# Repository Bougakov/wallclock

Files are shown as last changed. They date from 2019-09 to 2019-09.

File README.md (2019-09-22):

# Firmware for the clock in the hallway of http://sch57.ru

This is a firmware for a giant clock made of multiple layers of plywood and acrylic and five meters of "WS2812b" ("Neopixel") LED strip. It uses GPS module to set the correct time from satellites on the startup. RTC module ("DS1307") is used for timekeeping. 

During the lessons and in after-school hours it displays current time; during the breaks it acts as a count-down timer.

This clock is a part of a large-scale redesign of School 57 by a Russian architect and designer, Mia Karlova, which won the "Best public space" award by AD Magazine in https://www.admagazine.ru/ad-design-award/novyj-oblik-moskovskoj-shkoly-57 and was featured in FRAME magazine: https://www.frameweb.com/news/moscow-school-57-mia-karlova

Assembled clock on the wall

[Click to view video on Instagram: Preview - Instagram](https://www.instagram.com/p/BxpXTDVDegR/)

Initally, a large TV screen was used instead of this clock:

Old TV was replaced with this clock

The clock can be assembled from laser-cut sheets of 3-4mm plywood. The [layouts (in AutoCAD format)](https://github.com/Bougakov/wallclock/tree/master/CAD%20files%20%28plywood%20lasercut%29) are designed in such a way that any laser cutter with working area of as low as 300x600mm could be used. Few dozen of 40mm M3 screws are needed for assembly. Diffusors are made of 2mm matte acrylic.

[Click to view video on Instagram: Countdown - Instagram](https://www.instagram.com/p/B2cq6O_Ikv1/)

Click the preview of the AutoCAD drawing to read more on the assembly:

AutoCAD drawing in full glory

## Wiring

* GPS is connected (via "MAX232" RS232 to TTL converter) to `D3` pin of Arduino. Don't forget to double-check the baud rate of your GPS.
* LED strip (288 "WS2812" LEDs) – to pin `D2`.
  * Each "digit" is made of 7 segments, 10 LEDs each. 
  * "Colon" in the middle is made of 2 segments, 4 LEDs each.
* Controller – an Arduino Nano (Atmega 328P, "old bootloader")

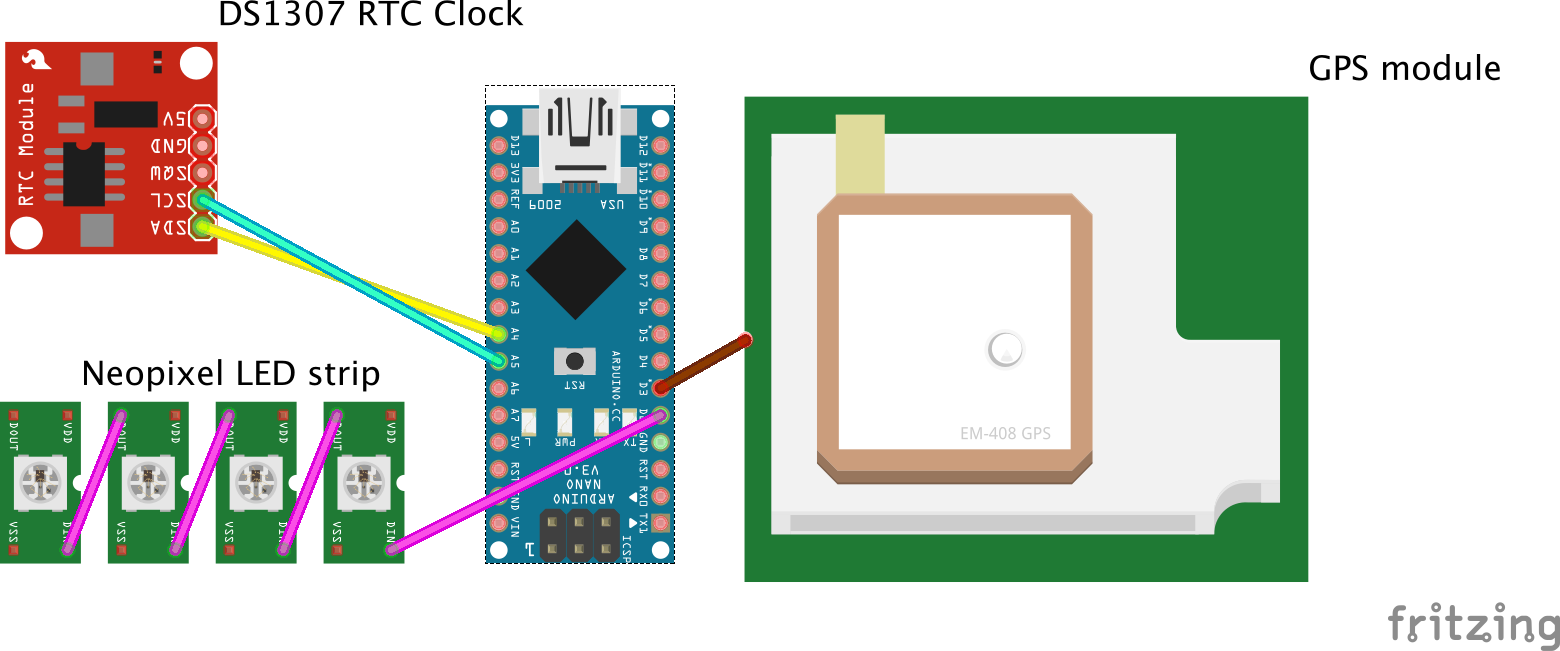
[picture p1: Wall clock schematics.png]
Wiring


## Important notes

Avoid voltage drop by wiring LED strip to external power source in multiple points.
For heat dissipation use 5m of 10mm aluminum strip cut to length of LED fragments. There are vent holes on the back that allow aluminum strips to dissipate heat to the wall. Fix the LEDs and strips using zip ties.

To radically simplify the programming of the clock make sure you connect the segments in each digit in the identical order. Check out attached Excel file to get the idea on how to do it. 

## Adjusting time table for your school:

To change the time ranges check out this code fragment:

```
  break2start = makeTime(year(local), month(local), day(local), 10, 40,  0);
  break2end   = makeTime(year(local), month(local), day(local), 10, 54, 59);
```

It tells Arduino that the break after the 2nd lesson is between 10:40am and 10:55. Please note that times entered here need to be in the local timezone, not UTC.

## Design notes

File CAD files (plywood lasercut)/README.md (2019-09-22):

# Laser cutting layouts

The design is authored in AutoCAD - the original intent was to prepare the layouts in such way that they would fit into 60x30cm workspace.

Clock is assembled from several layers using M3 bolts. Wires are fed through internal channels. Even and odd layers have different orientation (connecting faces look like arrows that point left on even layers and right at odd layers). Simply turn respective layers on and off before exporting the design to laser cutter:

AutoCAD layers

The thickness of plywood can be 4 or 5mm or even thicker - it doesn't matter. More layers is better (more distance from LEDs to the diffusor, more uniform lightning), but it takes more material and the clock gets heavier.

Cutting on a laser

The diffusors are best cut from matte acrylic. 

Acrylic faceplates

For best results add some styrofoam under the acrylic to diffuse light from individual Neopixels even more.

Add diffusors

The power supply and Arduino go in a separate box:

With a Box

Individual LED strips are attached to aluminum planks to help dissipating heat and held together using nylon zip ties. 

Zip ties

Make sure that you insulate the ends of the LED strips where they could accidentally touch aluminum.

Tape on the ends

Soldering that many strips feels tedious...

Heat dissipation

Here is the overall look (center part not painted yet):

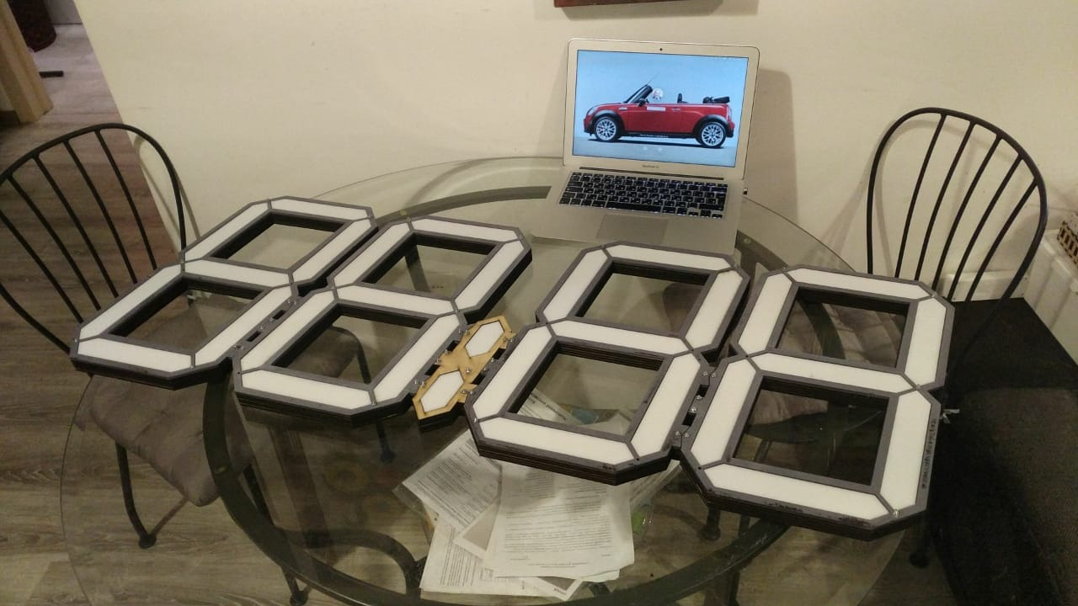
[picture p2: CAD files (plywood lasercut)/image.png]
Overall look


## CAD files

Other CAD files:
CAD files (plywood lasercut)/wall clock rev2_002.dwg

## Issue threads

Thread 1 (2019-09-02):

Зачем GPS?

MinerChAI, 2019-09-02:
Зачем GPS? Можно брать время со звонка. Тогда вне зависимости от того, где звонок берет время, часы будут показывать правильное время.

Bougakov, 2019-09-03:
В школе WiFi с RADIUS-авторизацией через портал госуслуг, ходить на NTP-сервер невозможно. Уже пробовали с RaspberryPi и WiFi, не выходит.

Контроллер звонка стоит на 1 этаже, а часы будут висеть на третьем.

Closed 2019-09-03.

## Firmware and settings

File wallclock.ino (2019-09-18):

#include <Time.h>             //https://github.com/PaulStoffregen/Time with patch from https://github.com/PaulStoffregen/Time/pull/131/files
#include <DS1307RTC.h>        //https://github.com/PaulStoffregen/DS1307RTC
#include <Timezone.h>         //https://github.com/JChristensen/Timezone
#include <TinyGPS++.h>        //https://github.com/mikalhart/TinyGPSPlus
#include <SoftwareSerial.h>
#include <Wire.h>

////////////////////////////////////
// INIT - GPS & REAL-TIME CLOCK
////////////////////////////////////

// Serial config for the GPS module
static const int RXPin = 3, TXPin = 13; // receive on pin 3, second pin is irrelevant
static const uint32_t GPSBaud = 4800; // "BR-355" GPS module uses 4800 baud speed. Cheaper "Neo6Mv2" uses 9600 baud. 

// The TinyGPS++ object
TinyGPSPlus gps;

// The serial connection to the GPS device
SoftwareSerial GPS_Serial(RXPin, TXPin);

tmElements_t tm;
bool rtcSet = false;

//Timezone stuff
int tzOff = 3; // plus three hours from UTC to Moscow time zone
TimeChangeRule ruMSK = {"MSK", Last, Sun, Mar, 1, tzOff * 60}; // number of hours * 60 mins in each hour = 180 minutes between UTC and Moscow
Timezone tzMSK(ruMSK, ruMSK); // For a time zone that does not change to daylight/summer time, we pass a single rule to the constructor

TimeChangeRule *tcr; //pointer to the time change rule, use to get TZ abbrev
time_t utc, local;

//variables for time counting
unsigned long previousMillis = 0;
unsigned long currentMillis = 0;
unsigned long syncTimer = 0;
unsigned long scheduledTimer = 0;

bool newboot = true;
int prevSecond = 0; // for debugging

////////////////////////////////////
// INIT - NEOPIXEL
////////////////////////////////////

#include <Adafruit_NeoPixel.h> // Adafruit NeoPixel library
#define PIN 2 // LED strip is wired to pin #2
#define NUMPIXELS 288 // total amount of NeoPixels attached to the Arduino

/*
  LED strip is connected as following. Please note that all four digits are wired identically, 
  so drawing numbers in any of the four available slots is done same way - you only have to shift
  by a necessary offset. I.e., to draw "1" in first or third slot you need to light up same amount of
  LEDs (twenty), the only difference is that you need to shift by 148 LEDs.

  1st digit - LEDs   0 to  69
  2nd digit - LEDs  70 to 139 (offset =  70)
  upper dot - LEDs 140 to 143 
  lower dot - LEDs 144 to 147
  3rd digit - LEDs 148 to 217 (offset = 148)
  4th digit - LEDs 218 to 287 (offset = 218)

      237 236 235 234 233 232 231 230 229 228             167 166 165 164 163 162 161 160 159 158                     89  88  87  86  85  84  83  82  81  80                  19  18  17  16  15  14  13  12  11  10  
  238                                         227     168                                         157             90                                          79          20                                          9
  239                                         226     169                                         156             91                                          78          21                                          8
  240                                         225     170                                         155             92                                          77          22                                          7
  241                                         224     171                                         154             93                                          76          23                                          6
  242                                         223     172                                         153             94                                          75          24                                          5
  243                                         222     173                                         152             95                                          74          25                                          4
  244                                         221     174                                         151             96                                          73          26                                          3
  245                                         220     175                                         150             97                                          72          27                                          2
  246                                         219     176                                         149             98                                          71          28                                          1
  247                                         218     177                                         148             99                                          70          29                                          0
      248 249 250 251 252 253 254 255 256 257             178 179 180 181 182 183 184 185 186 187                     100 101 102 103 104 105 106 107 108 109                 30  31  32  33  34  35  36  37  38  39  
  287                                         258     217                                         188     140     139                                         110         69                                          40
  286                                         259     216                                         189     141     138                                         111         68                                          41
  285                                         260     215                                         190     142     137                                         112         67                                          42
  284                                         261     214                                         191     143     136                                         113         66                                          43
  283                                         262     213                                         192             135                                         114         65                                          44
  282                                         263     212                                         193     144     134                                         115         64                                          45
  281                                         264     211                                         194     145     133                                         116         63                                          46
  280                                         265     210                                         195     146     132                                         117         62                                          47
  279                                         266     209                                         196     147     131                                         118         61                                          48
  278                                         267     208                                         197             130                                         119         60                                          49
      277 276 275 274 273 272 271 270 269 268             207 206 205 204 203 202 201 200 199 198                     129 128 127 126 125 124 123 122 121 120                 59  58  57  56  55  54  53  52  51  50  

*/

Adafruit_NeoPixel pixels(NUMPIXELS, PIN, NEO_GRB + NEO_KHZ800);

// default colors:
byte default_red   =  32;
byte default_green = 255;
byte default_blue  =  32;

// Variables to hold timetable of lessons:
time_t  break0start ;
time_t  break0end   ;
time_t  break1start ;
time_t  break1end   ;
time_t  break2start ;
time_t  break2end   ;
time_t  break3start ;
time_t  break3end   ;
time_t  break4start ;
time_t  break4end   ;
time_t  break5start ;
time_t  break5end   ;
time_t  break6start ;
time_t  break6end   ;
time_t  break7start ;
time_t  break7end   ;

unsigned int isSchoolbreak; // Are we in between lessons?
unsigned long countdownToBreak; // Countdown to next lesson' start.

////////////////////////////////////
// SETUP
////////////////////////////////////

void setup() {
  Serial.begin(115200);
  GPS_Serial.begin(GPSBaud);

  pixels.begin(); // Initializes NeoPixel strip object
  pixels.clear(); // Resets LED strip (turns all LEDs off)
  draw_GPS(default_red, default_green, default_blue);
  pixels.show(); // Sends the updated pixel colors to the hardware.
}

////////////////////////////////////
// MAIN LOOP
////////////////////////////////////

void loop() { 
  currentMillis = millis();
  if(!rtcSet){
    syncOnBoot();
  } else {
    setSyncProvider(RTC.get); // tells Arduino to get the time from the RTC
    time_t utc = now();
    local = tzMSK.toLocal(utc, &tcr);
    isSchoolbreak = 0;
    countdownToBreak = 0;
    schoolBreak(); // checks whether we are in between lessons
    handleLED(); // subroutine with all stuff that handles LED display
    debugTime(); // prints time to serial monitor
  }
}

////////////////////////////////////
// FUNCTIONS - TIMETABLE
////////////////////////////////////

void schoolBreak() { // sets times of lessons and breaks on current day (in UTC time zone)

  // #  Lesson starts Lesson ends Break starts  Break ends
  // 1 09:00 09:45 09:45 09:55
  // 2 09:55 10:40 10:40 10:55
  // 3 10:55 11:40 11:40 11:55
  // 4 11:55 12:40 12:40 12:55
  // 5 12:55 13:40 13:40 13:55
  // 6 13:55 14:40 14:40 14:55
  // 7 14:55 15:40 15:40 15:55
  // 8 15:55 16:40 16:40 

  // Times entered here need to be in the local timezone (I don't know why)
  break0start = makeTime(year(local), month(local), day(local),  8, 58,  0);
  break0end   = makeTime(year(local), month(local), day(local),  8, 59, 59);
  break1start = makeTime(year(local), month(local), day(local),  9, 45,  0);
  break1end   = makeTime(year(local), month(local), day(local),  9, 54, 59);
  break2start = makeTime(year(local), month(local), day(local), 10, 40,  0);
  break2end   = makeTime(year(local), month(local), day(local), 10, 54, 59);
  break3start = makeTime(year(local), month(local), day(local), 11, 40,  0);
  break3end   = makeTime(year(local), month(local), day(local), 11, 54, 59);
  break4start = makeTime(year(local), month(local), day(local), 12, 40,  0);
  break4end   = makeTime(year(local), month(local), day(local), 12, 54, 59);
  break5start = makeTime(year(local), month(local), day(local), 13, 40,  0);
  break5end   = makeTime(year(local), month(local), day(local), 13, 54, 59);
  break6start = makeTime(year(local), month(local), day(local), 14, 40,  0);
  break6end   = makeTime(year(local), month(local), day(local), 14, 54, 59);
  break7start = makeTime(year(local), month(local), day(local), 15, 40,  0);
  break7end   = makeTime(year(local), month(local), day(local), 15, 54, 59);

  if ((local >= break0start) && (break0end >= local)) {
    isSchoolbreak = 1;
    countdownToBreak = long(break0end - local);
  };

  if ((local >= break1start) && (break1end >= local)) {
    isSchoolbreak = 1;
    countdownToBreak = long(break1end - local);
  };

  if ((local >= break2start) && (break2end >= local)) {
    isSchoolbreak = 1;
    countdownToBreak = long(break2end - local);
  };
  
  if ((local >= break3start) && (break3end >= local)) {
    isSchoolbreak = 1;
    countdownToBreak = long(break3end - local);
  };
  
  if ((local >= break4start) && (break4end >= local)) {
    isSchoolbreak = 1;
    countdownToBreak = long(break4end - local);
  };
  
  if ((local >= break5start) && (break5end >= local)) {
    isSchoolbreak = 1;
    countdownToBreak = long(break5end - local);
  };
  
  if ((local >= break6start) && (break6end >= local)) {
    isSchoolbreak = 1;
    countdownToBreak = long(break6end - local);
  };
  
  if ((local >= break7start) && (break7end >= local)) {
    isSchoolbreak = 1;
    countdownToBreak = long(break7end - local);
  };

}

////////////////////////////////////
// FUNCTIONS - CLOCK
////////////////////////////////////

void syncOnBoot() {
  if(newboot) {

    // Read GPS data from serial connection until no more data is available
    while (GPS_Serial.available() > 0) {
      gps.encode(GPS_Serial.read());
    }

    if (currentMillis > 5000 && gps.charsProcessed() < 10) {
      Serial.println(F("No GPS detected: check wiring."));
      while(true); // halt
    }
 
    int satcount = gps.satellites.value();
    if (gps.date.isValid() && gps.time.isValid() && satcount >= 4) {
      Serial.print(F("New boot. Need to update RTC with GPS time. Sat count: "));
      Serial.println(satcount);

      Serial.println(F("Setting RTC from GPS"));
      if (gps.date.isValid() && gps.time.isValid()) {
        tm.Year   = gps.date.year();
        tm.Month  = gps.date.month();
        tm.Day    = gps.date.day();
        tm.Hour   = gps.time.hour();
        tm.Minute = gps.time.minute();
        tm.Second = gps.time.second();

        Serial.print(F("UTC time from GPS is: "));
        padZero(gps.time.hour());
        Serial.print(":");
        padZero(gps.time.minute()); 
        Serial.print(":");
        padZero(gps.time.second()); 
        Serial.println();
        
        // Saves GPS time to RTC
        if (RTC.write(tm)) {
          Serial.println(F("RTC is now set from GPS."));
          rtcSet = true;
          newboot = false;
          syncTimer = 0;
          GPS_Serial.end(); // stops processing GPS data until clock is rebooted (useful since SoftwareSerial messes with hardware timers and causes clock to drift)
          setSyncProvider(RTC.get); // tells Arduino to get the time from the RTC
          time_t utc = now();
          local = tzMSK.toLocal(utc, &tcr);
          if(timeStatus()!= timeSet) {
            Serial.println(F("Unable to sync with the RTC, check wiring! "));
            while(true); // halt
          } else {
            Serial.println(F("Initialized the RTC."));
          }
        } else {
          Serial.println(F("Error setting RTC from GPS values: check wiring."));
          while(true); // halt
        }
      } else {
        Serial.println(F("No GPS fix yet. Can't set RTC yet."));
      }

    } else {
      if(currentMillis > (syncTimer + 250)) {
        Serial.print(F("GPS not ready yet. Waiting for fix. Sat count: "));
        Serial.println(satcount);
        syncTimer = currentMillis;
      }
    }
  }
}

void debugTime() {
  if(!rtcSet)  {
    Serial.println(F("Waiting for GPS Fix"));
  } else {
    if (second(local) != prevSecond){
      padZero(  hour(local));
      Serial.print(":");
      padZero(minute(local)); 
      Serial.print(":");
      padZero(second(local)); 
      Serial.println();
    
      // Serial.print(F("Are we in a break? "));
      // Serial.println(isSchoolbreak);
      // Serial.print(F("Countdown to next lesson: "));
      // Serial.println(countdownToBreak);
    }
    prevSecond = second(local);
  }
}

void padZero(int digits){
  // utility function for digital clock display: prints preceding colon and leading 0
  if(digits < 10) {
    Serial.print('0');
  }
  Serial.print(digits);
}

////////////////////////////////////
// FUNCTIONS - LED STRIP
////////////////////////////////////

void draw_GPS(int red, int green, int blue) {
  // Draws four characters, "GPS…", on the LED strip while we get correct time from satellites
  /*
    G: 228-237, 238-247, 278-287, 268-277, 258-267
    P: 148-157, 158-167, 168-177, 178-187, 208-217
    S: 80-89, 90-99, 100-109, 110-119, 120-129
    hellip: 50-51, 54-55, 58-59
  */
  pixels.clear(); // Set all pixel colors to 'off'
  strip(228, 237, 0, red, green, blue); 
  strip(238, 247, 0, red, green, blue); 
  strip(278, 287, 0, red, green, blue); 
  strip(267, 277, 0, red, green, blue); 
  strip(258, 267, 0, red, green, blue); 
  strip(148, 157, 0, red, green, blue); 
  strip(158, 167, 0, red, green, blue); 
  strip(168, 177, 0, red, green, blue); 
  strip(178, 187, 0, red, green, blue); 
  strip(208, 217, 0, red, green, blue); 
  strip( 80,  89, 0, red, green, blue); 
  strip( 90,  99, 0, red, green, blue); 
  strip(100, 109, 0, red, green, blue); 
  strip(110, 119, 0, red, green, blue); 
  strip(120, 129, 0, red, green, blue); 
  strip( 50,  50, 0, red, green, blue); 
  strip( 54,  54, 0, red, green, blue); 
  strip( 58,  58, 0, red, green, blue); 
  pixels.show();
}

void handleLED() { // Main routine that handles displaying time on LED strip:
  pixels.clear(); // Set all pixel colors to 'off'
  if(isSchoolbreak == 0) {
    drawtime(default_red, default_green, default_blue); // Displays current time
  } else {
    drawcountdown(int(countdownToBreak));
  }
  pixels.show();   // Sends the updated pixel colors to the hardware.  
}

void drawtime(int red, int green, int blue) {
  int h =   hour(local);
  int m = minute(local);

  // placeholders for upper and lower digits of time - i.e. "11:23" - "3" is lower minute digit, "2" is upper
  int h_lo_digit = h % 10;
  int h_hi_digit = (h - h_lo_digit) / 10;
  int m_lo_digit = m % 10;
  int m_hi_digit = (m - m_lo_digit) / 10;

  drawdigit(h_hi_digit, 4, red, green, blue);  // leftmost position (4th from right)
  drawdigit(h_lo_digit, 3, red, green, blue);  
  drawdigit(m_hi_digit, 2, red, green, blue);  
  drawdigit(m_lo_digit, 1, red, green, blue);  // rightmost position

  if ((millis() % 800) >= 400) {
    // blinks with colon every 400ms
    draw_upper_dot(red, green, blue); 
    draw_lower_dot(red, green, blue); 
  }
}

void drawcountdown(int cnt) { // displays the countdown - time left till next lesson starts

  // conversion from "duration" in seconds to mm:ss:
  int ss = cnt % 60;        // seconds left till end of break
  int mm = (cnt - ss) / 60; // minutes left

  // placeholders for upper and lower digits of time
  int mm_lo_digit = mm % 10;
  int mm_hi_digit = (mm - mm_lo_digit) / 10;
  int ss_lo_digit = ss % 10;
  int ss_hi_digit = (ss - ss_lo_digit) / 10;

  // for the final 60 seconds before the bell rings we switch color from violet to red:
  byte countdown_red;
  byte countdown_green;
  byte countdown_blue;
  if (cnt >= 59) { 
    countdown_red   = 255;
    countdown_green =   0;
    countdown_blue  = 255;
  } else {
    countdown_red   = 255;
    countdown_green =   0;
    countdown_blue  =   0;
  }

  drawdigit(mm_hi_digit, 4, countdown_red, countdown_green, countdown_blue);  // leftmost position (4th from right)
  drawdigit(mm_lo_digit, 3, countdown_red, countdown_green, countdown_blue);  
  drawdigit(ss_hi_digit, 2, countdown_red, countdown_green, countdown_blue);  
  drawdigit(ss_lo_digit, 1, countdown_red, countdown_green, countdown_blue);  // rightmost position

  if ((millis() % 400) >= 200) {
    // blinks with colon every 200ms
    draw_upper_dot(countdown_red, countdown_green, countdown_blue); 
    draw_lower_dot(countdown_red, countdown_green, countdown_blue); 
  }
}

void strip(int start, int end, int offset, int red, int green, int blue) {
  // Sub-routine to draw a given sequence of LEDs in a given RGB color
  for (int i = (start + offset); i <= (end + offset); i = i + 1) { 
    pixels.setPixelColor(i, pixels.Color(red, green, blue)); 
  }
}

// Sub-routines to draw a colon in the center of the clock (eight LEDs) in a given RGB color
void draw_upper_dot(int red, int green, int blue) {
  for (int i = 140; i <= 143; i = i + 1) { 
    pixels.setPixelColor(i, pixels.Color(red, green, blue)); 
  }
}

void draw_lower_dot(int red, int green, int blue) {
  for (int i = 144; i <= 147; i = i + 1) { 
    pixels.setPixelColor(i, pixels.Color(red, green, blue)); 
  }
}
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

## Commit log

2019-05-25 Added Excel file used to identify LEDs
    [Numbering of LEDs on the strip.xlsx]
2019-09-01 Added schematics
2019-09-01 Added schematics
    SVG didn't work
2019-09-05 Fixed an error that caused clock to run late
    Root cause: SoftwareSerial hijacked hardware interrupts and millis() skipped cycles. Also: needed to put "setSyncProvider(RTC.get);" in the loop to make constant syncs to RTC.
    [wallclock.ino]
2019-09-15 Timetable prototype
2019-09-16 Added note on wiring LEDs
2019-09-18 Added photo of final assembly
2019-09-18 Changes countdown timer to MM:SS, fixes colors
    [wallclock.ino]
